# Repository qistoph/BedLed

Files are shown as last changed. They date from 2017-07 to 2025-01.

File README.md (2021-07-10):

# BedLed

## Video
BedLed in action (https://www.youtube.com/watch?v=FOfo3qLnq14)

In this video you see the switches I've chosen. These are [5V metal momentary switches](https://www.aliexpress.com/snapshot/0.html?productId=32697109472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) along with [a socket](https://www.aliexpress.com/snapshot/0.html?productId=32811846605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).

These switches have 5 pins, with the following colors attached on the socket:
1. Red - LED Source (+)
2. Black - LED Ground (-)
3. White - Normally Open (NO)
4. Green - Common (C)
5. Blue - Normally Closed (NC)

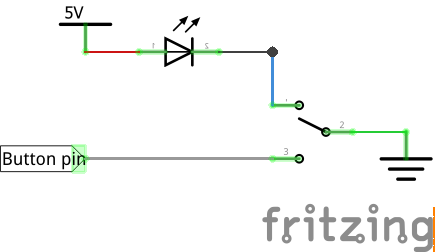
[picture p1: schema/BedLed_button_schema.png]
Schema


When the button is released NC is connected to C and NO is not connected.
When the button is pressed NO is connected to C and NC is not connected.

I have connected + to 5V, - to NC, NO to my button pin, C to ground. So when the button is not pressed, current flows from - through NC, to C, to ground, connecting the LED - to ground.
When the button is pressed, the LED flow is interrupted and the LED turns of (signaling the user a confirmation of the pressing). The button pin on the ATtiny is then connected through NO to ground.

## Schema
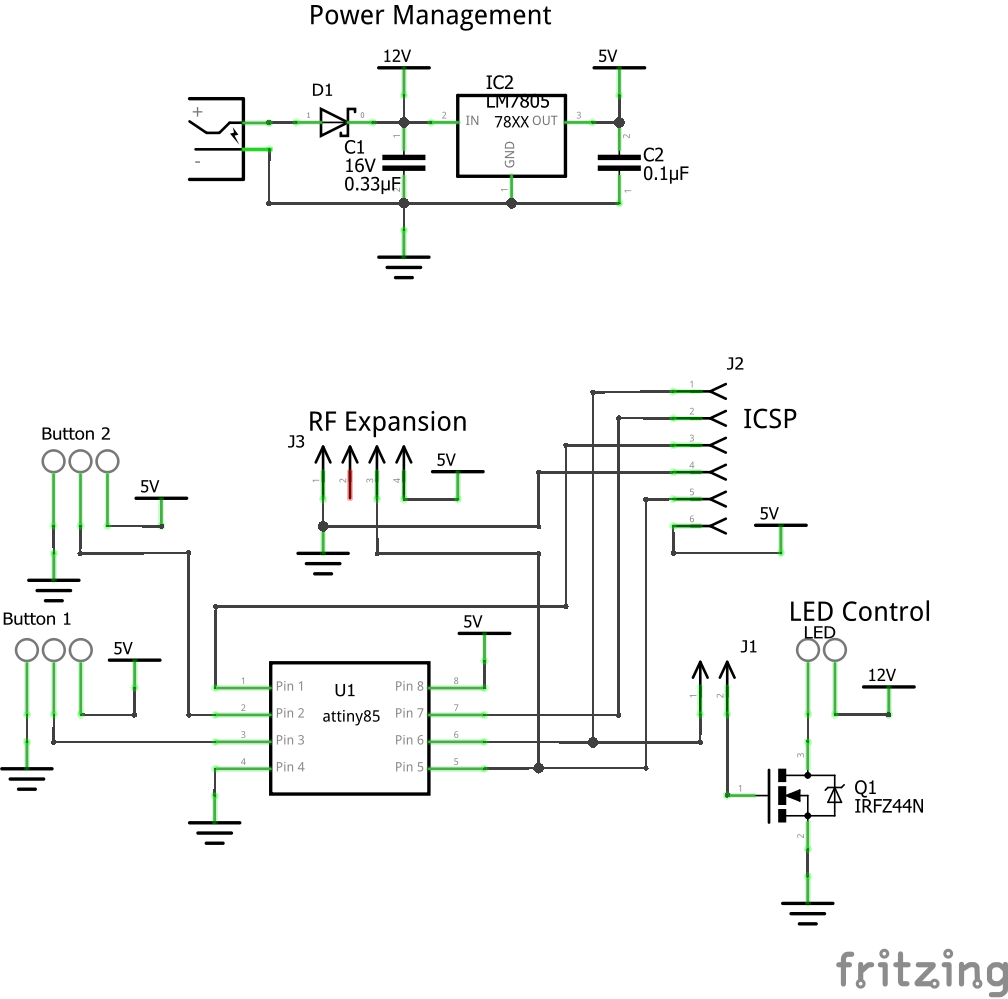
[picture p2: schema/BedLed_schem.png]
Schema


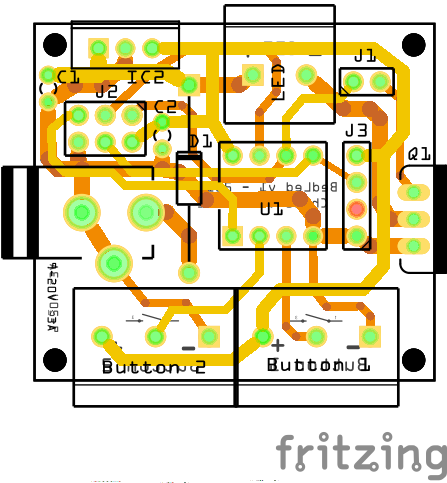
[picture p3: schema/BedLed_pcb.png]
PCB


Also available on [Aisler](https://aisler.net/qistoph/bedled/main-pcb)

## Parts
- D1 - Skottky diode (20V, 3A)
- C1 - 16V, 0.33µF
- C2 - 5V, 0.1µF
- IC2 - LM7805
- Q1 - IRFZ44N
- U1 - ATtiny85
- J1 - 2 pin header with jumper
- Power supply socket
- Terminals for button and LED connections
- Buttons

Optional:
- J2 - 2x3 pin ICSP header (optional)
- RF expansion (e.g. 433 MHz receiver)
- Reset button (with 2-pin connector)

Connector pins:
- J1, 1 - Pin 6 (PB1, MISO)
- J1, 2 - Q1 gate

J1 - Jumper options:
- 1-2: Pin 6 (PB1) connected to Q1 gate

J2 - ICSP
- 1: MISO
- 2: VCC
- 3: SCK
- 4: MOSI
- 5: RESET
- 6: GND

J3 - RF expansion
- 1: GND
- 2: NC
- 3: Data
- 4: VCC

A serial connection with status/debug info (at 9600 baud) is available on J2-3 (SCK) which is connected to U1-PB2.

The optional reset button can be connected to J2-5,6. Computer power/reset switches are very suitable for this.

## Flashing
To prevent interruptions and blinking the LED strip during flashing:
- Disconnect the MOSFET by removing the jumper on J1 (freeing pin 6 - MISO)
- Remove the RF expansion (freeing pin 5 - MOSI)

## Version 2
After years of use I've made some software improvements in version 2.

The KlikAaanKlikUit module and code is removed. I've never managed to get a remote to work from more than half a meter away and have given up on it.

In the dark we sometimes would like to turn on the light, but really dimm. To enable this I have added an even dimmer setting (1/255 PWM). Additionally if the button is held while turning on, it turns on with the dimmest option.

To quickly turn on the brightest a simple double click will suffice.

Additional clicks immediately after turning on will cycle through other modes.

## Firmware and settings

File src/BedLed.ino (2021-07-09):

// NOTE!!!
// Uses:
// ATTinyCore (https://github.com/SpenceKonde/ATTinyCore)
// TinyDebugSerial (https://github.com/qistoph/TinyDebugSerial) + modified to use PB2 on F_CPU<=8MHz

// Fuse/Core config:
// Timer 1 Clock: 64MHz
// Clock: 8MHz internal

//TODO:
// Check datasheet page 99 for required frequency

// LED_PIN must support PWM,
#define LED_PIN 1
#define BTN1_PIN 3
#define BTN2_PIN 4
#define TX 2 // As used hardcoded by TinyDebugSerial

// Times are in ms
// DEBOUNCE_DELAY: time to allow jitter on a button before accepting its new state
// DIMM_TIMEOUT:   time to wait, after pressing a button, before starting to dimm
// DIMM_STEP_TIME: time between stepping to the next dimm level
#define DEBOUNCE_DELAY 20
#define DIMM_TIMEOUT 1000
#define DIMM_STEP_TIME 500

// End of configuration

#if 1 // 1 -> Use TinyDebugSerial, 0 -> Use core Serial (+428 bytes)
  #include <TinyDebugSerial.h>
  TinyDebugSerial TDSerial;
  #define MySerial TDSerial
#else
  #define MySerial Serial
#endif

#ifndef SIGRD // used in boot.h by boot_signature_byte_get_short(addr)
#define SIGRD RSIG
#endif

bool deepSleepEnabled = true;

bool lightIsOn = false;

void setup() {
  // put your setup code here, to run once:
  OSCCAL = 0x6F;
  MySerial.begin(9600);

  Serial.println(F("Running setup"));
  buttonsSetup();
  lightSetup();

  // Setup interrupts
  *digitalPinToPCICR(BTN1_PIN) |= _BV(digitalPinToPCICRbit(BTN1_PIN)); // Enable PIN interrupts in general and btn1 pin
  *digitalPinToPCICR(BTN2_PIN) |= _BV(digitalPinToPCICRbit(BTN2_PIN)); //TODO: remove? (because same register in ATTiny)

  *digitalPinToPCMSK(BTN1_PIN) |= _BV(digitalPinToPCMSKbit(BTN1_PIN)); // Enable interrupt on button 1
  *digitalPinToPCMSK(BTN2_PIN) |= _BV(digitalPinToPCMSKbit(BTN2_PIN)); // Enable interrupt on button 2

  MySerial.println(F("Blink LED"));
  lightOn();
  delay(500);
  lightOff();
}

uint8_t wasTouching = false;
unsigned long loopStart = 0;
unsigned long sleepAt = 0;
unsigned long eeStart = 0;
bool startEe = false;

extern bool lightIsOn;

// Interrupt handler, called for button and RF interrupts
ISR(PCINT0_vect) {
}

void loop() {
  loopStart = millis();

  uint8_t stableTouch = buttonsReadTouch();

  if(stableTouch != wasTouching) {
    //Serial.print("stableTouch: ");
    //Serial.println(stableTouch);

    // state change
    if(stableTouch && !wasTouching) {
      // Release -> Touch
      MySerial.println(F("Touch"));
      onTouch();
    } else if(!stableTouch && wasTouching) {
      // Touch -> Release
      MySerial.println(F("Release"));
      onTouchRelease();
    }
    wasTouching = stableTouch;
  } else if(stableTouch) {
    // Still touching
    onTouching();
  }

  if(stableTouch == 3) {
    if(eeStart == 0) {
      eeStart = millis() + 2000;
      startEe = true;
    } else if(millis() > eeStart && startEe) {
      MySerial.println(F("EASTER EGG MODE!"));
      easterEgg();
      startEe = false;
    }
  } else {
    eeStart = 0;
  }

  touchLoop();

//  Serial.print(F("lightIsOn: "));
//  Serial.println(lightIsOn);
//  Serial.print(F("stableTouch: "));
//  Serial.println(stableTouch);
//  Serial.print(F("deepSleepEnabled: "));
//  Serial.println(deepSleepEnabled);
  if(!lightIsOn && millis() > sleepAt && deepSleepEnabled) {
    deepSleep();
    sleepAt = millis() + 100; // Allow at least 100ms to detect button presses before sleeping again
  }
}

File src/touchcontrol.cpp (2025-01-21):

#include "touchcontrol.h"
#include "lightcontrol.h"
#include "modes.h"
#include "quake.h"

byte releaseAction = RELEASE_CLICK;
unsigned long touchStartedAt = 0;

#define MODE_NORMAL 0
#define MODE_BRIGHT 1
#define MODE_BREATH 2
#define MODE_STROBE 3
#define MODE_HORROR 4
#define MODE_QUAKE  5
#define NUM_MODES   6

byte mode = MODE_NORMAL;

void onTouch() {
  touchStartedAt = millis();
  releaseAction = RELEASE_CLICK;

  randomSeed(analogRead(0));
}

void onTouching() {
  switch(mode) {
    case MODE_NORMAL:
    case MODE_BRIGHT:
      if(millis() > (touchStartedAt + DIMM_TIMEOUT)) {
        if(!lightIsOn) {
          MySerial.println(F("Dimmed on"));
          lightSetDimm(dimmLevelMin);
          lightOn();
        } else {
          MySerial.println(F("Dimming"));
          lightDimm();
        }
        
        releaseAction = RELEASE_HOLD;

        // Hack: set touchStartedAt so that after DIMM_STEP_TIME the DIMM_TIMEOUT is reached again
        // triggering this if() every DIMM_STEP_TIME ms
        touchStartedAt = millis() - (DIMM_TIMEOUT - DIMM_STEP_TIME);
      }
      break;
    case MODE_STROBE:
      if(millis() > (touchStartedAt + DIMM_TIMEOUT)) {
        if(strobe_freq_hz < 10) {
          strobe_freq_hz = 10;
        } else if(strobe_freq_hz < 20) {
          strobe_freq_hz = 20;
        } else if(strobe_freq_hz < 30) {
          strobe_freq_hz = 30;
        } else if (strobe_freq_hz < 40) {
          strobe_freq_hz = 40;
        } else {
          strobe_freq_hz = 5;
        }
        
        MySerial.print(F("Strobe freq (Hz): "));
        MySerial.println(strobe_freq_hz);

        releaseAction = RELEASE_SKIP;

        touchStartedAt = millis() - (DIMM_TIMEOUT - DIMM_STEP_TIME);
      }
      break;
    case MODE_QUAKE:
      if(millis() > (touchStartedAt + DIMM_TIMEOUT)) {
        uint8_t quake_mode = nextQuake();

        MySerial.print(F("Quak mode: "));
        MySerial.println(quake_mode);

        releaseAction = RELEASE_SKIP;
        touchStartedAt = millis() - (DIMM_TIMEOUT - DIMM_STEP_TIME);
      }
      break;
    default:
      // Nothing special, but hold should not turn off the light
      if(millis() > (touchStartedAt + DIMM_TIMEOUT)) {
        releaseAction = RELEASE_SKIP;
      }
      break;
  }
}

void nextMode() {
  mode = (mode + 1) % NUM_MODES;
  MySerial.print(F("Mode: "));
  MySerial.println(mode);

  switch (mode)
  {
    case MODE_BRIGHT:
        lightSetDimm(dimmLevelMax);
      break;
  }
}

unsigned long lastClick = 0;

void onTouchRelease() {
  MySerial.print(F("releaseAction: "));
  MySerial.print(releaseAction);

  switch(releaseAction) {
    case RELEASE_CLICK:
      MySerial.println(F(" (RELEASE_CLICK)"));

      if (lightIsOn) {
        if (millis() - lastClick < DOUBLE_CLICK_TIME) {
          nextMode();
        } else {
          lightOff();
          mode = MODE_NORMAL;
        }
      } else {
        lightOn();
      }

      lastClick = millis();
      break;
    case RELEASE_HOLD:
      MySerial.println(F(" (RELEASE_HOLD)"));
      // Save the current dimm level to EEPROM
      lightSaveData();
      break;
    case RELEASE_SKIP:
      MySerial.println(F(" (RELEASE_SKIP)"));
      break;
    default:
      MySerial.println(F(" (Unknown)"));
      break;
  }
}

void easterEgg() {
  releaseAction = RELEASE_SKIP;
  mode = MODE_BREATH;
}

void touchLoop() {
  switch(mode) {
    case MODE_BREATH:
      lightBreathe();
      break;
    case MODE_STROBE:
      lightStrobe();
      break;
    case MODE_HORROR:
      lightHorror();
      break;
    case MODE_QUAKE:
      lightQuake();
      break;
  }
}

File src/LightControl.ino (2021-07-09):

#include "Storage.h"

// ZERO terminated list of available dimmLevels
int dimmLevels[] = {8, 16, 32, 64, 128, 255};
int dimmLevel = 8;

void lightSetup() {
  pinMode(LED_PIN, OUTPUT);
  eepromLoad(STORAGE_DIMM_ADDRESS, &dimmLevel, sizeof(dimmLevel));
  if(dimmLevel < dimmLevels[0]) {
    dimmLevel = dimmLevels[0];
  }
}

void lightSaveData() {
  eepromSave(STORAGE_DIMM_ADDRESS, &dimmLevel, sizeof(dimmLevel));
}

void lightOn() {
  //TODO: move setup to lightSetup
  // LSM   - 0 - Low Speed Mode
  // [6:3] - R
  // PCKE  - 0 - Disable PCK (PLL as clock), wait for PLL Lock first
  // PLLE  - 1 - Enable PLL
  // PLOC  - R
  PLLCSR = _BV(PLLE); // Start PLL, No Low Speed Mode
  delayMicroseconds(100);
  while (!(PLLCSR & (1<<PLOCK))); //Wait for PLL lock
  PLLCSR |= _BV(PCKE); // Use PLL as clock source

  OCR1C = 255 - 1;
  OCR1A = dimmLevel;

  // CTC1       -    1 - Reset timer after compare match with OCR1C (p.89)
  // PWM1A      -    1 - Enable PWM mode (p.89)
  // COM1A[1:0] -   01 - OC1A cleared on compare match, set when TCNT1 = $00. (!OC1A) set on compare match, cleared when TCNT1 = $00. (p.86)
  // CS1[3:0]   - 0010 - PCK/2 (p.88)
  TCCR1 = _BV(CTC1) | _BV(PWM1A) | 0 | _BV(COM1A0) | 0 | 0 | _BV(CS11) | 0;
  lightIsOn = true;
  MySerial.println(F("On"));
}

void lightOff() {
  TCCR1 = 0; // Disable timer 1
  lightIsOn = false;
  MySerial.println(F("Off"));
}

byte delayAtMaxCounter = 0;
void lightDimm() {
  if(dimmLevel == dimmLevels[sizeof(dimmLevels) - 1]) {
    // Current value is the last one
    // Delay a little
    if(delayAtMaxCounter > 0) {
      delayAtMaxCounter--;
      return;
    }

    delayAtMaxCounter = 2;
    dimmLevel = dimmLevels[0];
  } else {
    for(uint8_t n=0; n<sizeof(dimmLevels); ++n) {
      if(dimmLevel < dimmLevels[n]) {
        dimmLevel = dimmLevels[n];
        break;
      }
    }
  }
  
  MySerial.print(F("dim: "));
  MySerial.println(dimmLevel);
  lightOn(); // Turn light 'on' to effectuate dimm
}

void lightSetDimm(int dimm) {
  dimmLevel = dimm;
  lightOn(); // Turn light 'on' to effectuate dimm
}

void lightBlink(uint8_t count) {
  for(;count;) {
    lightOn();
    delay(250);
    lightOff();
    if(--count) {
      delay(250);
    }
  }
}

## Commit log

2016-12-28 Add schema
    [BedLed.fzz]
2016-12-30 Multiple changes
    [BedLed.fzz]
2017-01-11 Fix pins for TinyDebugSerial
    [BedLed.ino]
2017-01-13 Use ATTinyCore and Fast PWM
2017-01-17 Use bigger connectors, add plugin-ins
    [BedLed.fzz]
2017-01-17 Add connector descriptions
2017-01-17 Remove power plug description
    [BedLed.fzz]
2017-01-21 Improve cap.sense performance
    [BedLed.fzz]
2017-06-27 Use buttons instead of cap sense
2017-06-29 Replace cap sense with buttons in schema
    [BedLed.fzz]
2017-06-29 Add single ICSP header
    [BedLed.fzz]
2017-06-30 Minor updates
    [BedLed.fzz]
2017-07-01 OSCCAL, better morse, fix button reading
    [BedLed.fzz]
2017-07-03 Adjust PWM frequency
2017-07-06 Enable deepSleep with buttons on boot
2017-07-08 Test and fix deep sleep
    [BedLed.ino, LightControl.ino, TouchControl.ino]
2017-07-10 Remove debug prints
2017-07-10 Add VCC to button terminals add space
    [BedLed.fzz]
2017-07-10 Minor schema fixes
    [BedLed.fzz]
2017-07-10 Add expansion port for RF module
    [BedLed.fzz]
2017-07-18 Add KAKU handling, move some code around
    [BedLed.fzz]
2017-07-18 Track light status for kaku
2017-07-18 Clear up, restore EGG print, remove 3 sec timeout to exit learning mode
2017-08-23 Add button schema
2017-08-23 Add button wiring description and image
2018-06-16 Add button schema file
    [BedLed_button_schema.fzz]
2021-07-09 Use cpp/h files and arduinoisp
2021-07-09 FIX: bug in dimmlevels because of int size
    [lightcontrol.cpp]
2021-07-09 Skip lightOn in lightSetDimm. Do set dimm level for PWM
    [lightcontrol.cpp]
2021-07-09 Mode switching
2021-11-16 Include fuse settings in comments
2021-11-18 Add Quake lighting
    Based on https://github.com/Pakequis/arduino-quake-flicker-lamp
